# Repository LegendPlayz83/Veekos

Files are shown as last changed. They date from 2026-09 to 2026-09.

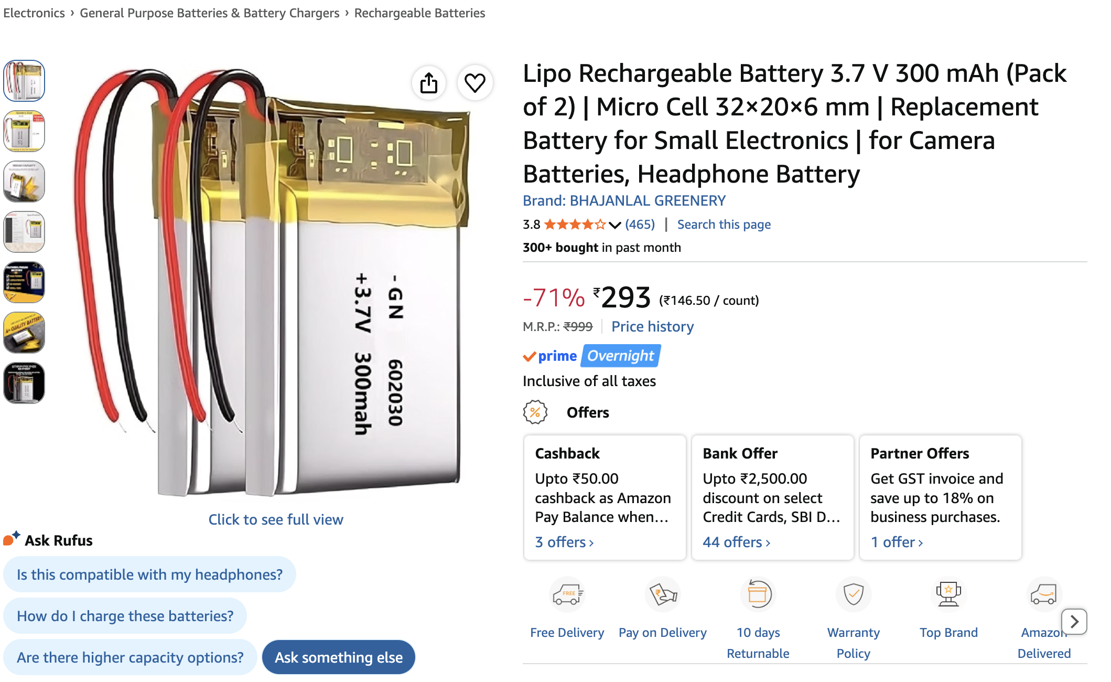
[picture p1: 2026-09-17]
Carts/Amazon-battery.png

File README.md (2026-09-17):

# Veekos
Veekos-full

Veekos is a 21-key wireless Bluetooth Macropad that uses the XIAO nRF52840 Sense as its microcontroller chip. Each key has its own diode assigned; the diodes are 1N4148.<br>

<h3>About the project</h3>
It has 21 keys, and its connectivity is through Bluetooth. <br>
In the design, you may see that there is no sign of the battery. This is because the Xiao already has an SMD space for connecting the battery, so I do not need to connect it to any pins.  <br>
 <br>

<h3>Why I made this</h3>
I have made many small macro pads consisting of 4-6keys, but this time, I wanted to go big with 21 keys. Also, this one is going to be connected via Bluetooth, giving me a huge relief from wired macro pads. 

<h3>Challenges faced</h3>
Although there were no major problems or challenges, while making its case, I had to change the measurement of the top part twice to make it match the bottom part. <br>
Also, I had to put the 3d model for each key manually in the KiCad PCB editor, along with removing the silkscreen of each key. This was a tedious task, but I did it :)

<h2>Schematic</h2>
Screenshot 2026-09-17 at 8 14 47 PM

<h2>PCB(without silkscreen art)</h2>
Screenshot 2026-09-17 at 8 15 34 PM

<h2>PCB(with silkscreen art)</h2>
Screenshot 2026-09-17 at 8 16 14 PM

<h2>PCB(3D view)</h2>
Screenshot 2026-09-17 at 8 18 13 PM

<h2>BOM</h2>

| Name | Quantity | Cost | Link |
| :--- | :---: | :---: | :--- |
| XIAO nrf52840 sense | 1 | $24.05 | [Robu.in](https://robu.in/product/seeed-studio-xiao-nrf52840-sense-tinyml-tensorflow-lite-imu-microphone-bluetooth5-0/) |
| PCB (from JLCPCB) | 1 | $20.45 | [JLCPCB](https://jlcpcb.com/) |
| 1N4148 Diodes | 21 | $2.00 (Self-funded) | [Amazon](https://amzn.in/d/07wEWb6X) |
| 3.7V LiPo Battery | 1 | $3.06 | [Amazon](https://amzn.in/d/050THvbC) |
| TP4056 Charger Module | 1 | $1.20 | [Amazon](https://amzn.in/d/01OvmiZk) |
| DSA Keycaps gradient | 1 | $6.40 | [Curiosity Caps](https://curiositycaps.in/products/21-keys-numpad-thick-pbt-cherry-pbt-keycaps) |
| Cherry MX Keys | 21 | $6.30 | [StacksKB](https://stackskb.com/store/click-inc-of-linear-switch-pack-of-10/) |
| Stainless steel screws | 4 | $2.00 (Self-funded) | [StacksKB](https://stackskb.com/store/m2-screw-8mm-stainless-steel/) |
| 2u Stabilizers | 3 | $3.45 | [StacksKB](https://stackskb.com/store/genuine-cherry-mx-plate-mount-stabilizers-2u/) |
| Shipping | 1 | $2.00 | [StacksKB](https://stackskb.com) |
| **Total** | — | **$68.91** | — |
| **Total funding required** | — | **$64.91** | — |
## Total Pricing
The total price comes out to be 6043 INR ($63) [ SHIPPING INCLUDED ]

The pricing might slightly vary due to flash sales, and dollar market trends.

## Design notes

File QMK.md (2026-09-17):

## Flashing & Configuring the Macropad

Steps to install the firmware and configure the Macropad:-

### 1. Download the .uf2 file from repo
Download it and save it on your computer locally

### 2. Enter Boot Mode on the Xiao
1. Unplug the Xiao from your computer.
2. Hold down the **BOOTSEL** button on the Xiao.
3. While holding the button, plug the Xiao into your computer using a USB cable.
4. The computer will detect a new drive, namely **RPI-RP2**.

### 3. Flash the Firmware
1. Download the `.uf2` firmware file from this repo.
2. Drag and drop the file onto the **RPI-RP2** drive.

Once the file finishes copying, the Xiao will reboot automatically.

### 5. Configure the Keymap
You can customise the Macropad layout in the .json file and keymap. c.c

Open the file in a text editor and edit the keymap section to match the layout.  
After saving the file, the Macropad will automatically reload with the new configuration.

### 6. Test the Macropad
Unplug and reconnect the Macropad, open a text editor, and press some keys to make sure everything works.

KABOOMMMM 
ITS DONNEEE

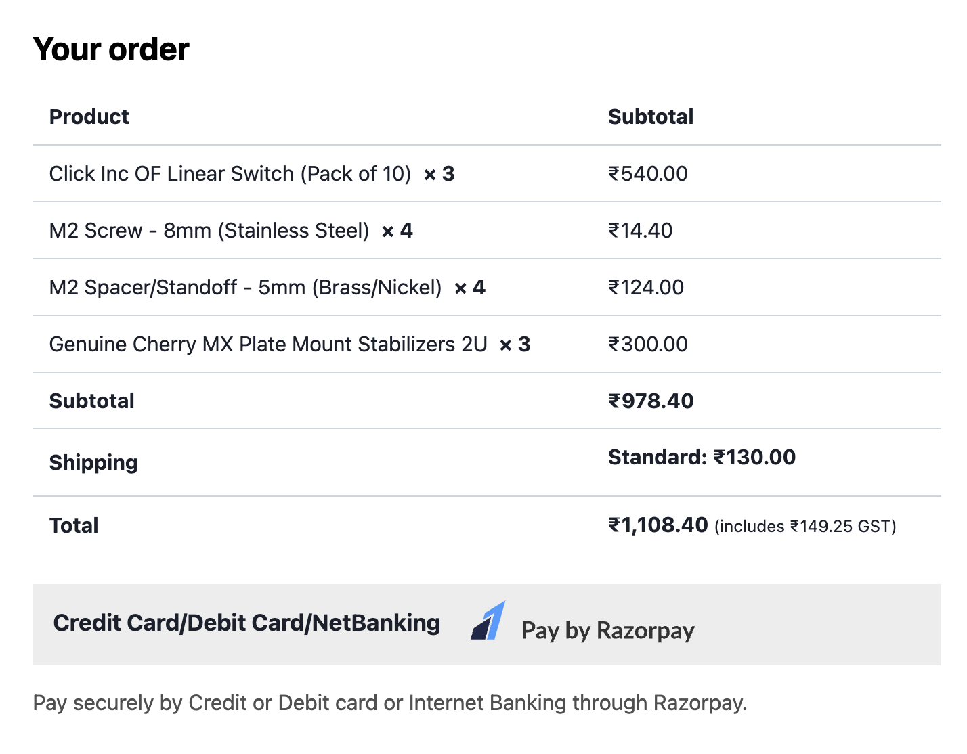
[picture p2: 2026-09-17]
Carts/StacksKB.png

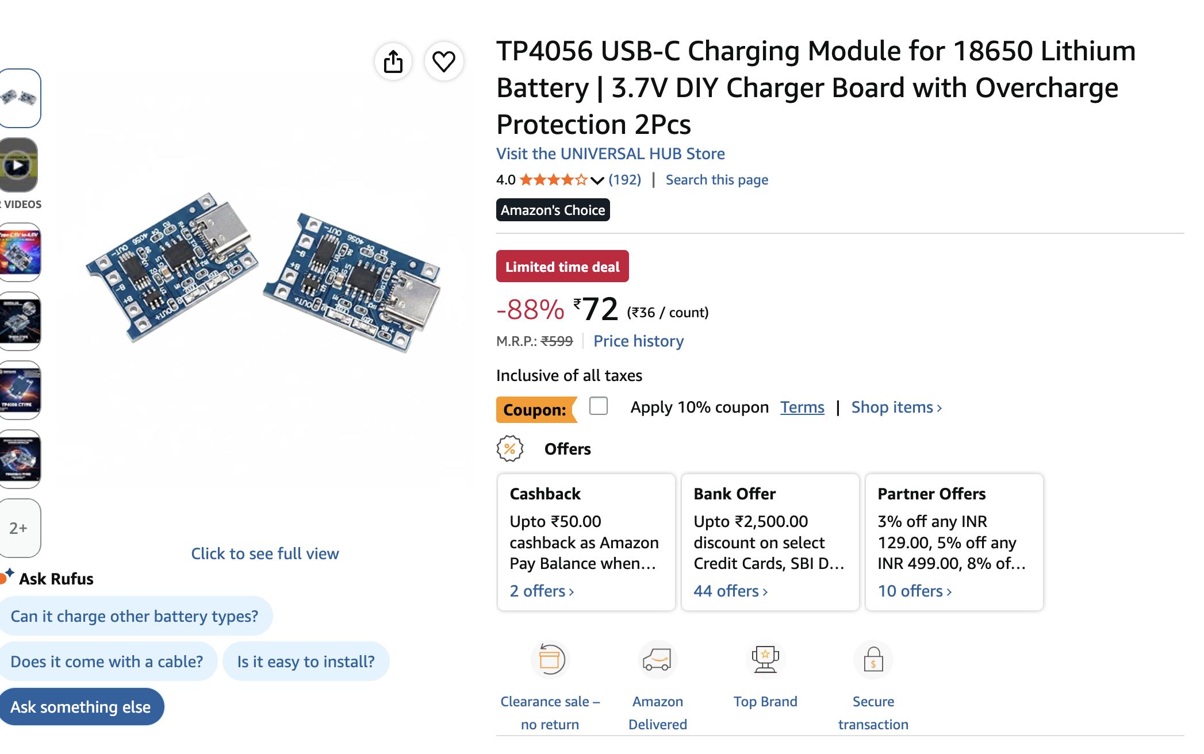
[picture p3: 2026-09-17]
Carts/Amazon-charger.png

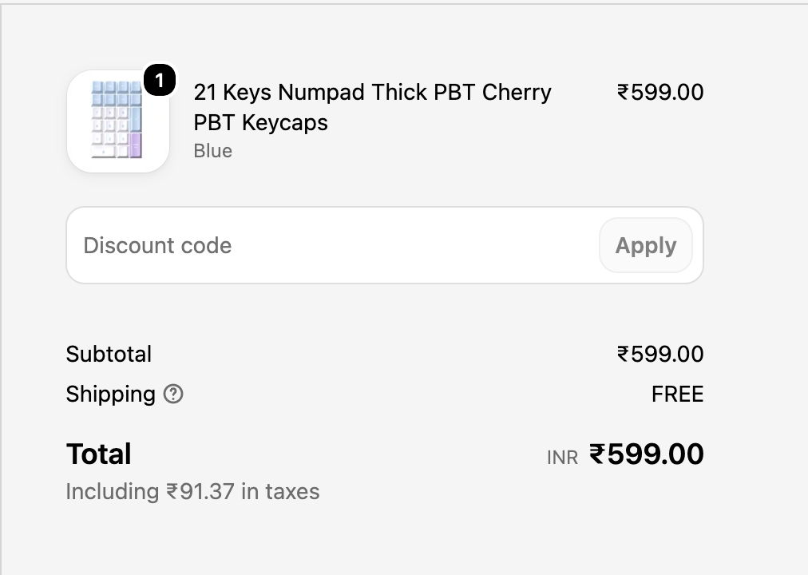
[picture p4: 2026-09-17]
Carts/CurosityCaps.png

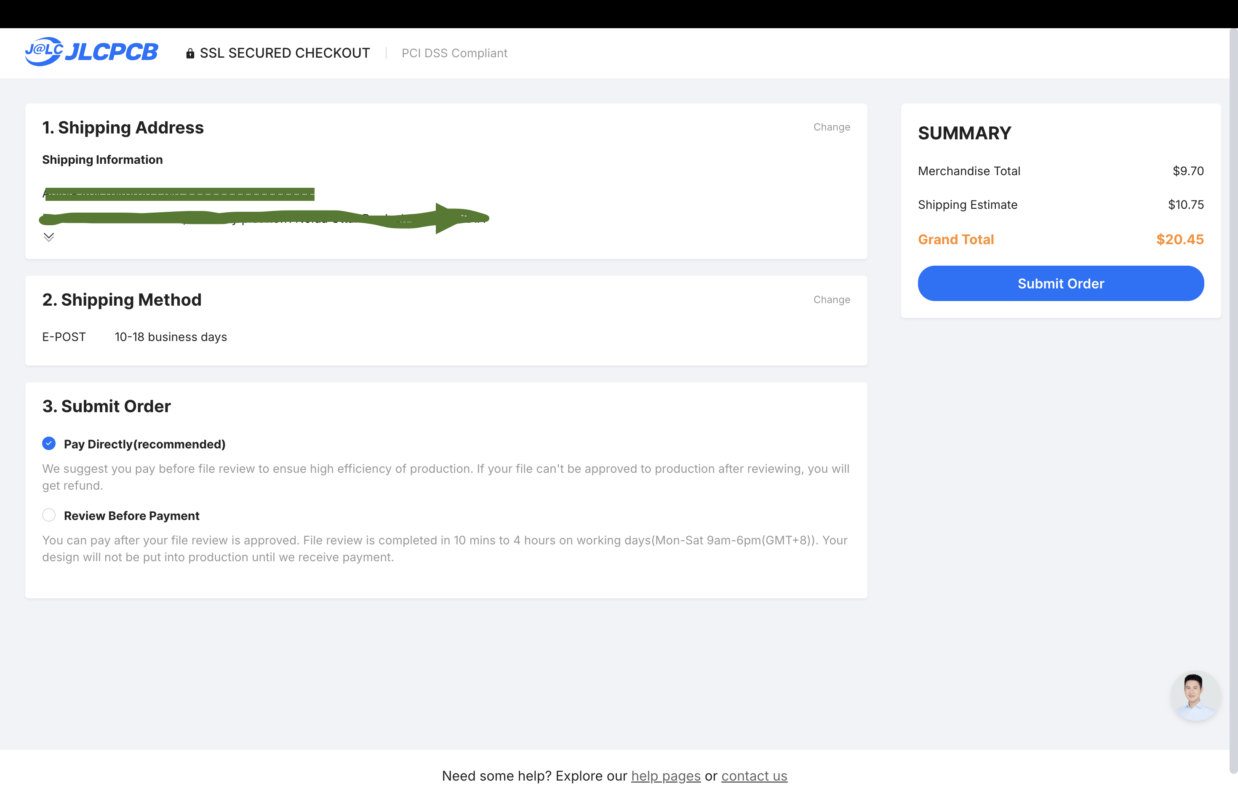
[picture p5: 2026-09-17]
Carts/JLCPCB.png

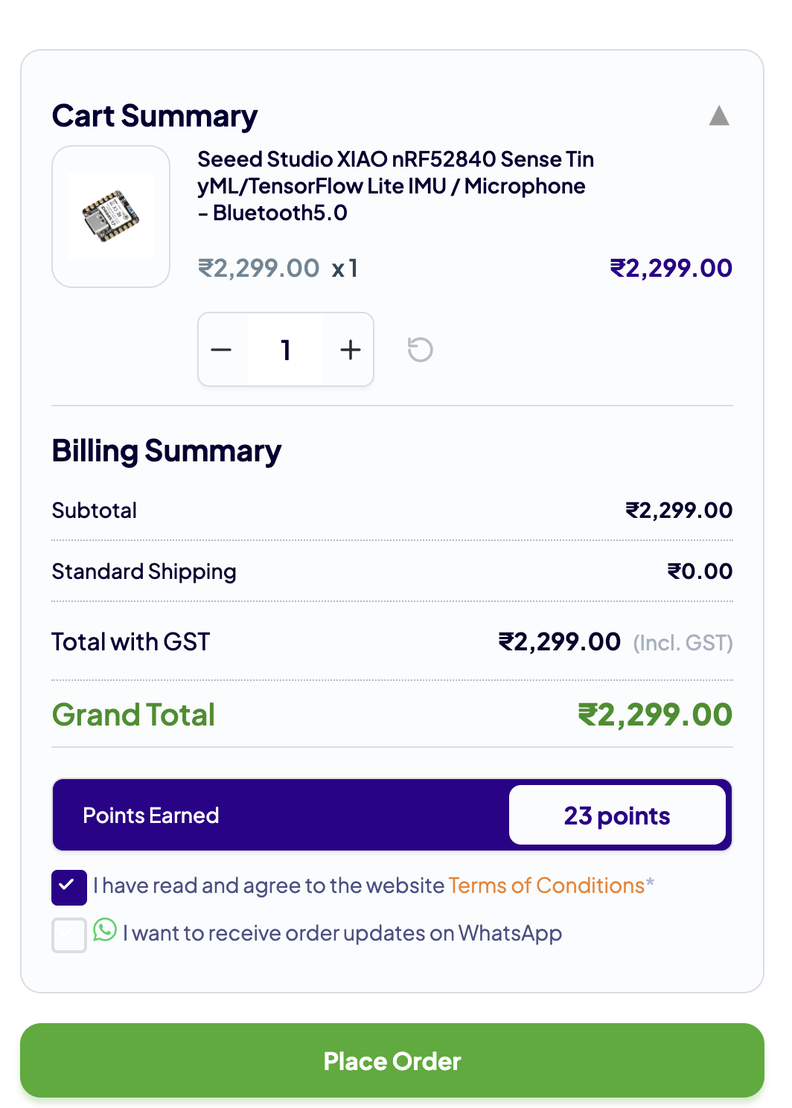
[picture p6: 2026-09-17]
Carts/Robu.png

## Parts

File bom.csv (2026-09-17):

Name | Quantity | Cost | Link
XIAO nrf52840 sense | 1 | $24.05 | https://robu.in/product/seeed-studio-xiao-nrf52840-sense-tinyml-tensorflow-lite-imu-microphone-bluetooth5-0/
PCB (from JLCPCB) | 1 | $20.45 | https://jlcpcb.com/
1N4148 Diodes | 21 | $2 (Self-funded) | https://amzn.in/d/07wEWb6X
3.7v LiPo Battery | 1 | $3.06 | https://amzn.in/d/050THvbC
TP4056 Charger Module | 1 | $1.20 | https://amzn.in/d/01OvmiZk
DSA Keycaps gradient | 1 | $6.40 | https://curiositycaps.in/products/21-keys-numpad-thick-pbt-cherry-pbt-keycaps
Cherry MX Keys | 21 | $6.30 | https://stackskb.com/store/click-inc-of-linear-switch-pack-of-10/
Stainless steel screws | 4 | 2 (Self-funded) | https://stackskb.com/store/m2-screw-8mm-stainless-steel/
2u Stablizers | 3 | $3.45 | https://stackskb.com/store/genuine-cherry-mx-plate-mount-stabilizers-2u/
Shipping | 1 | $2.00 | https://stackskb.com
Total |  | $66.91
Total funding required |  | $63.00

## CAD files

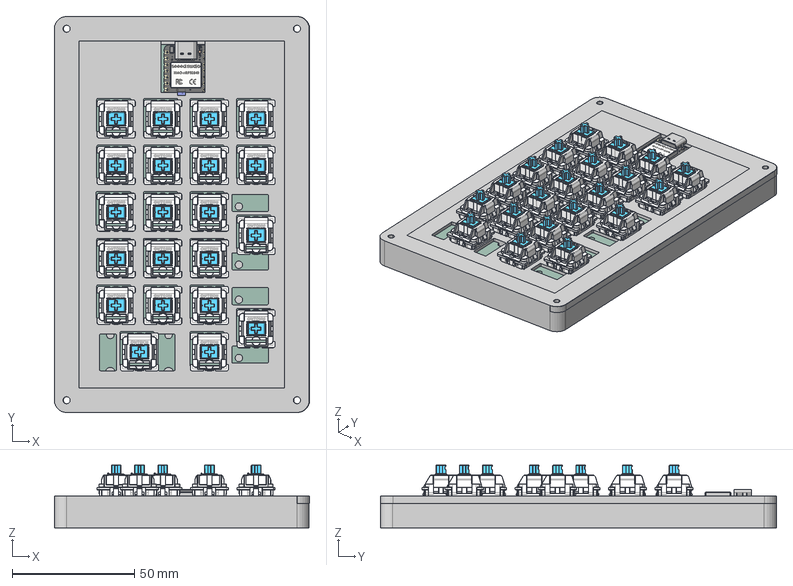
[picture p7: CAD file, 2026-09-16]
3D files/Veekos-full.step
104.3 x 161.8 x 25.7 mm
BOTT x 21
PIN x 21
SPRIN x 21
CLICK x 21
RET x 21
TOP x 21
BOSS-EXTRUDE14_8_
BOSS-EXTRUDE7_4_
BOSS-EXTRUDE7_3_
BOSS-EXTRUDE14_4_
BOSS-EXTRUDE14_2_
BOSS-EXTRUDE14_11_
BOSS-EXTRUDE7_7_
BOSS-EXTRUDE14_9_
BOSS-EXTRUDE14_3_
BOSS-EXTRUDE14_7_
MIRROR2
BOSS-EXTRUDE14_5_
BOSS-EXTRUDE14_12_
BOSS-EXTRUDE7_8_
BOSS-EXTRUDE7_1_
BOSS-EXTRUDE14_10_
BOSS-EXTRUDE7_9_
BOSS-EXTRUDE14_6_
BOSS-EXTRUDE14_1_
BOSS-EXTRUDE7_6_
BOSS-EXTRUDE7_2_
CUT-EXTRUDE5
BOSS-EXTRUDE7_5_
Shield
Pins
CAP x 2
ANT1
Silkscreen
CAP 3
led
USR
D_DO-35_SOD27_P7.62mm_Horizontal_1 x 21
veekos_PCB

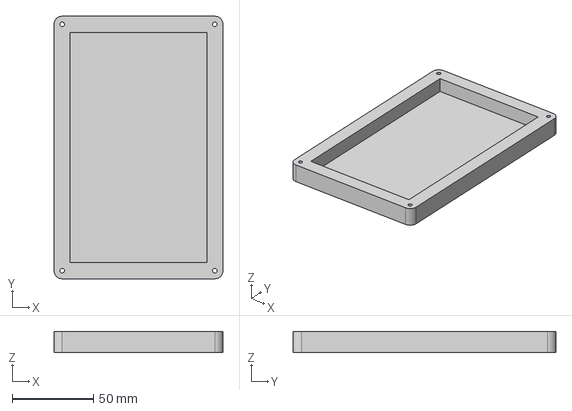
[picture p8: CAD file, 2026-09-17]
3D files/Veekos-bottom.step
104.1 x 161.8 x 13.0 mm

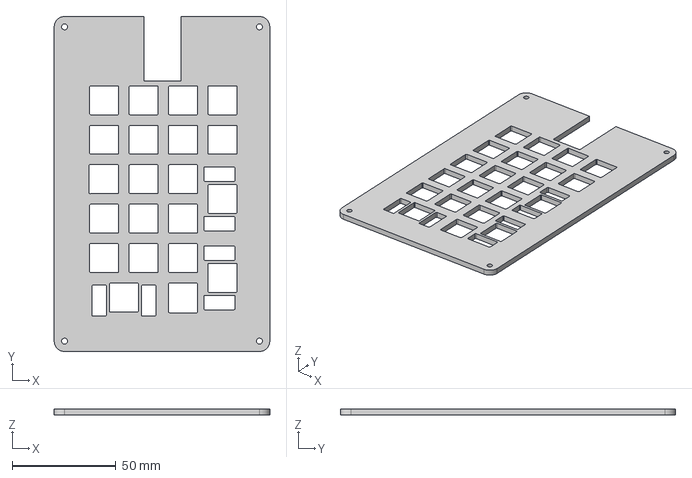
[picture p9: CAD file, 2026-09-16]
3D files/Veekos-top.step
104.1 x 161.8 x 3.00 mm

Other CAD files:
3D files/Veekos-bottom.f3d
3D files/Veekos-full.f3z
3D files/Veekos-top.f3d

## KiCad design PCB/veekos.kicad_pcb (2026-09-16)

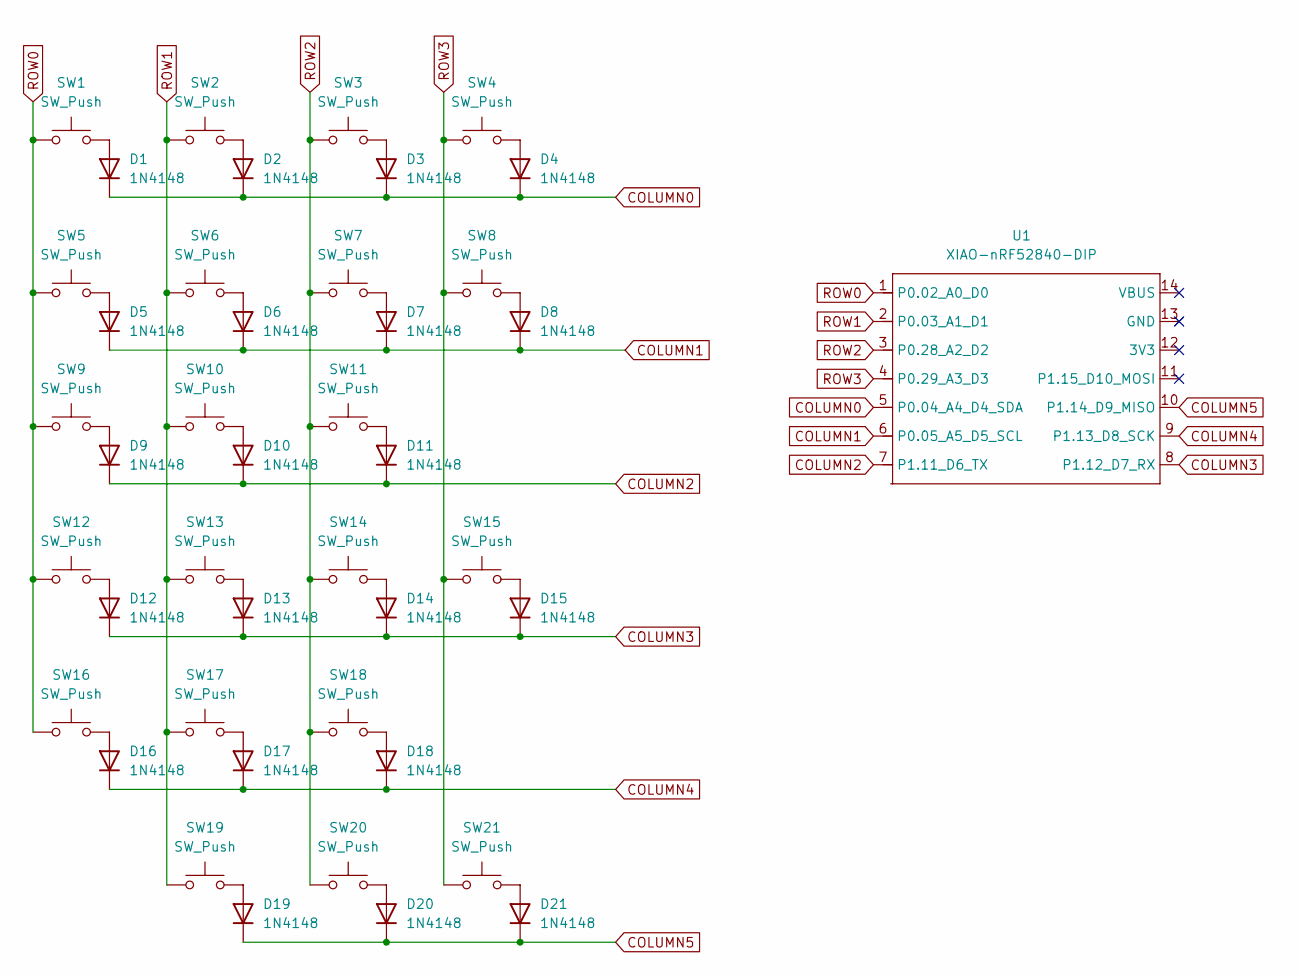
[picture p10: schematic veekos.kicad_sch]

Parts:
D1, D2, D3, D4, D5, D6, D7, D8, D9, D10, D11, D12, D13, D14, D15, D16, D17, D18, D19, D20, D21: 1N4148; D_DO-35_SOD27_P7.62mm_Horizontal
SW1, SW2, SW3, SW4, SW5, SW6, SW7, SW8, SW9, SW10, SW11, SW12, SW13, SW14, SW16, SW17, SW18, SW21: SW_Push; SW_Cherry_MX_1.00u_PCB
SW15, SW19: SW_Push; SW_Cherry_MX_2.00u_Vertical_PCB
SW20: SW_Push; SW_Cherry_MX_2.00u_PCB
U1: XIAO-nRF52840-DIP

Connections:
COLUMN0: D1.1 (K), D2.1 (K), D3.1 (K), D4.1 (K), U1.5 (P0.04_A4_D4_SDA)
COLUMN1: D5.1 (K), D6.1 (K), D7.1 (K), D8.1 (K), U1.6 (P0.05_A5_D5_SCL)
COLUMN2: D9.1 (K), D10.1 (K), D11.1 (K), U1.7 (P1.11_D6_TX)
COLUMN3: D12.1 (K), D13.1 (K), D14.1 (K), D15.1 (K), U1.8 (P1.12_D7_RX)
COLUMN4: D16.1 (K), D17.1 (K), D18.1 (K), U1.9 (P1.13_D8_SCK)
COLUMN5: D19.1 (K), D20.1 (K), D21.1 (K), U1.10 (P1.14_D9_MISO)
unnamed: D1.2 (A), SW1.2
unnamed: D2.2 (A), SW2.2
unnamed: D3.2 (A), SW3.2
unnamed: D4.2 (A), SW4.2
unnamed: D5.2 (A), SW5.2
unnamed: D6.2 (A), SW6.2
unnamed: D7.2 (A), SW7.2
unnamed: D8.2 (A), SW8.2
unnamed: D9.2 (A), SW9.2
unnamed: D10.2 (A), SW10.2
unnamed: D11.2 (A), SW11.2
unnamed: D12.2 (A), SW12.2
unnamed: D13.2 (A), SW13.2
unnamed: D14.2 (A), SW14.2
unnamed: D15.2 (A), SW15.2
unnamed: D16.2 (A), SW16.2
unnamed: D17.2 (A), SW17.2
unnamed: D18.2 (A), SW18.2
unnamed: D19.2 (A), SW19.2
unnamed: D20.2 (A), SW20.2
unnamed: D21.2 (A), SW21.2
ROW0: SW1.1, SW5.1, SW9.1, SW12.1, SW16.1, U1.1 (P0.02_A0_D0)
ROW1: SW2.1, SW6.1, SW10.1, SW13.1, SW17.1, SW19.1, U1.2 (P0.03_A1_D1)
ROW2: SW3.1, SW7.1, SW11.1, SW14.1, SW18.1, SW20.1, U1.3 (P0.28_A2_D2)
ROW3: SW4.1, SW8.1, SW15.1, SW21.1, U1.4 (P0.29_A3_D3)

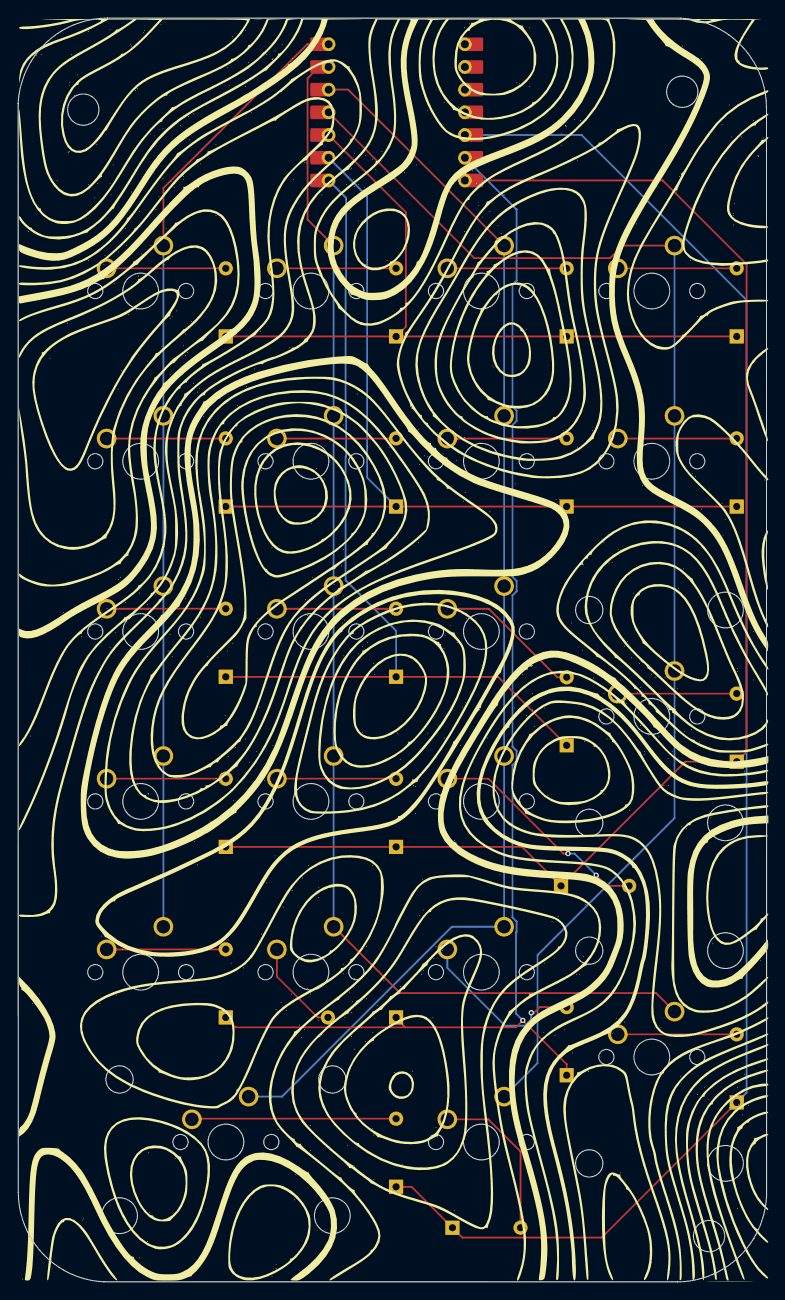
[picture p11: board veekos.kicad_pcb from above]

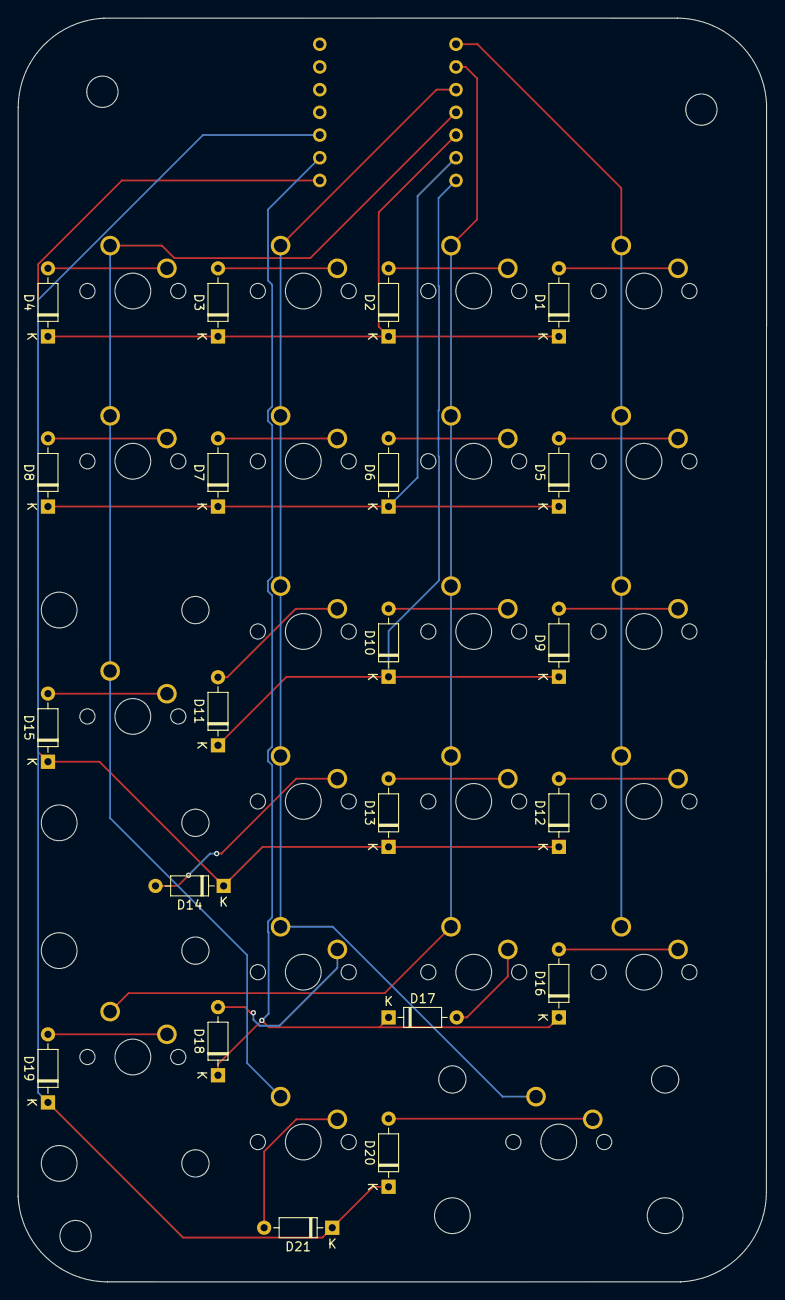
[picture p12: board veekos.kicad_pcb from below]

Board: 2 copper layers, 83.7 x 141.4 mm, 43 parts (21 on the bottom side), 31 nets.

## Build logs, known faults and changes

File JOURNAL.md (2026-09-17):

---
title: "Veekos"
author: "adr"
description: "Veekos is a 21-key wireless Bluetooth Macropad that uses XIAO nrf52840 sense as its microcontroller chip. Each key has its own diode"
created_at: "2026-05-10"
---

# 2026-09-17: Writing firmware

**Total time spent: 2.8 hours**

Since there was a change of plans between Xiao RP2040 and and nrf52840 sense. So, my time was not fully tracked through Hackatime. 


# 2026-09-16: Assembly

**Total time spent: 0.56 hours**

After finishing the PCB and case, I had to assemble everything. I started by exporting the PCB from KiCad, then used Fusion's feature to insert components. I inserted the bottom case first, and then aligned its height to the PCB accordingly. Then I imported the top case and aligned it with the rest. Final look:


# 2026-09-16: Making case

**Total time spent: 2.19 hours**

Bottom Case:










Top part:





Forgot the mounting holes :p, had to redo the whole



# 2026-09-15: Adding 3D model

**Total time spent: 0.7 hours**

After I was done with the routing and technical stuff, I had to add the 3D model for each component. This also had to be done manually, component by component. 


# 2026-09-15: Routing and silkscreen changes

**Total time spent: 2.8 hours**

After placing all the keys and diodes, I wired them to the XIAO nrf52840 sense, and then I made the edges of the pcb curved. Now, for the silkscreen, i removed each line and edge of the silkscreen of each key manually so that i could cover the whole pcb in a beautiful silkscreen. This part took time since you had to go in edit footprint for each key one by one and then select the silkscreen edges, careful not to select anything else and then delete. Look before silkscreen(after routing):

And then final look:


# 2026-05-16: PCB making time!!!

**Total time spent: 2.4 hours**

First, I arranged all the keys together, with precision up to three decimal places. 
Screenshot 2026-05-10 at 9.12.41 PM.png

And after that, I also placed all the diodes 
Screenshot 2026-05-12 at 7.19.20 PM.png

# 2026-05-11: Schematic

**Total time spent: 2.5 hours**

I went through some macropads, and the 21-key macropad looked the best to me. I chose this layout and made its rough matrix on the image


After that, in the Kicad schematic, I placed all the symbols together according to the matrix along with the XIAO. 
sch-no wire.png

After that, I wired all the keys together


After wiring all the keys together, I connected everything to the XIAO and closed the unused ports
 

Finally, in the schematic, I assigned all the footprints carefully according to the layout:


Done with the schematic, now moving on to PCB
